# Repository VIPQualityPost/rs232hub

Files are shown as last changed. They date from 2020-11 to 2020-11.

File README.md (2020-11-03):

# rs232hub
This is a small project to make a USB-RS232 four port hub for use with SCPI commands for making an easy, automated testing controller. 
I successfully made the prototype with just one channel, but for the final design I want to incorporate a 4 port USB hub controller so I can have several devices connected at once.
I don't need USB3.0 speed so this will not include that, but it will feature a USB-C port to be consistent with other designs I have made (and I still have several connectors left over from previous projects)

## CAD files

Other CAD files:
Sketch.step
usbfootprint.FCStd

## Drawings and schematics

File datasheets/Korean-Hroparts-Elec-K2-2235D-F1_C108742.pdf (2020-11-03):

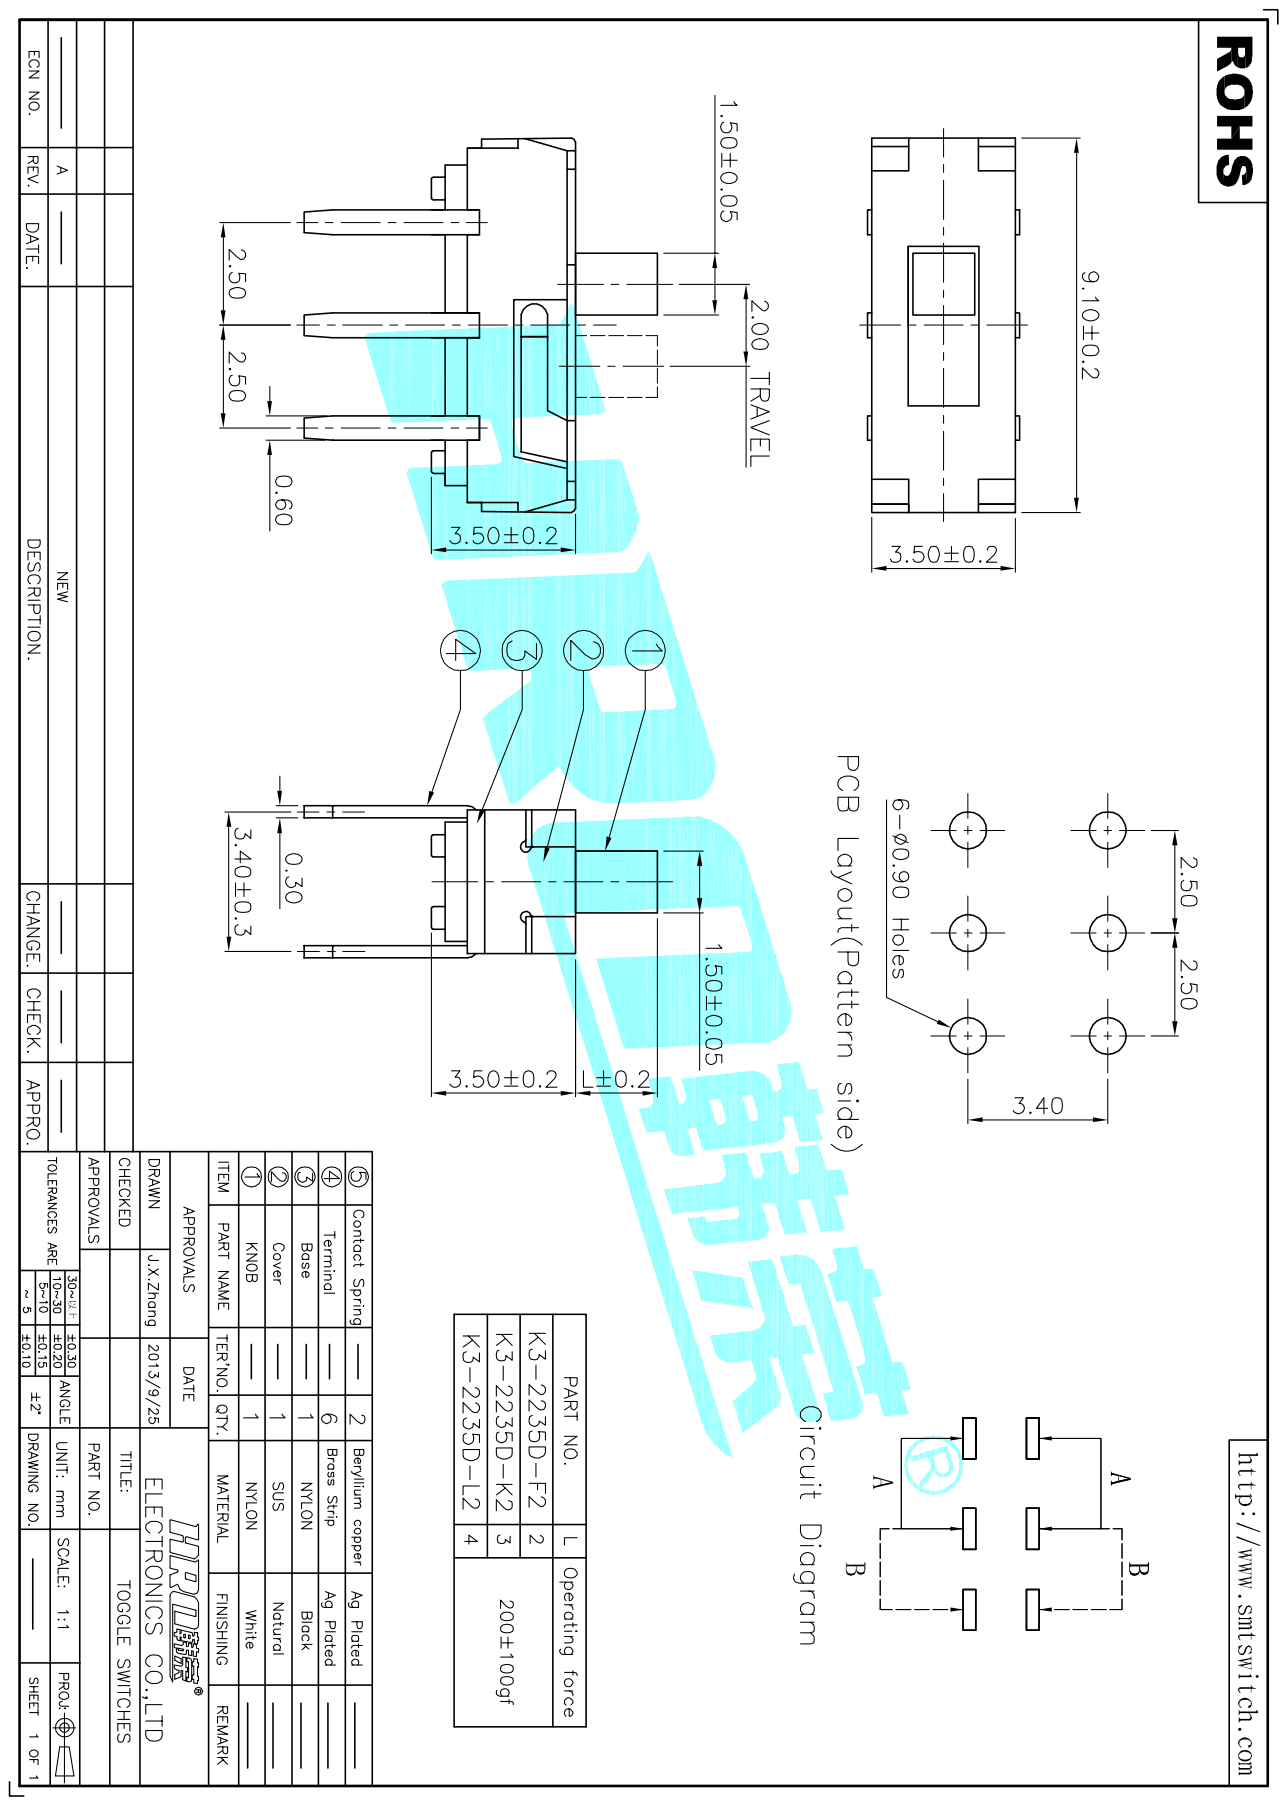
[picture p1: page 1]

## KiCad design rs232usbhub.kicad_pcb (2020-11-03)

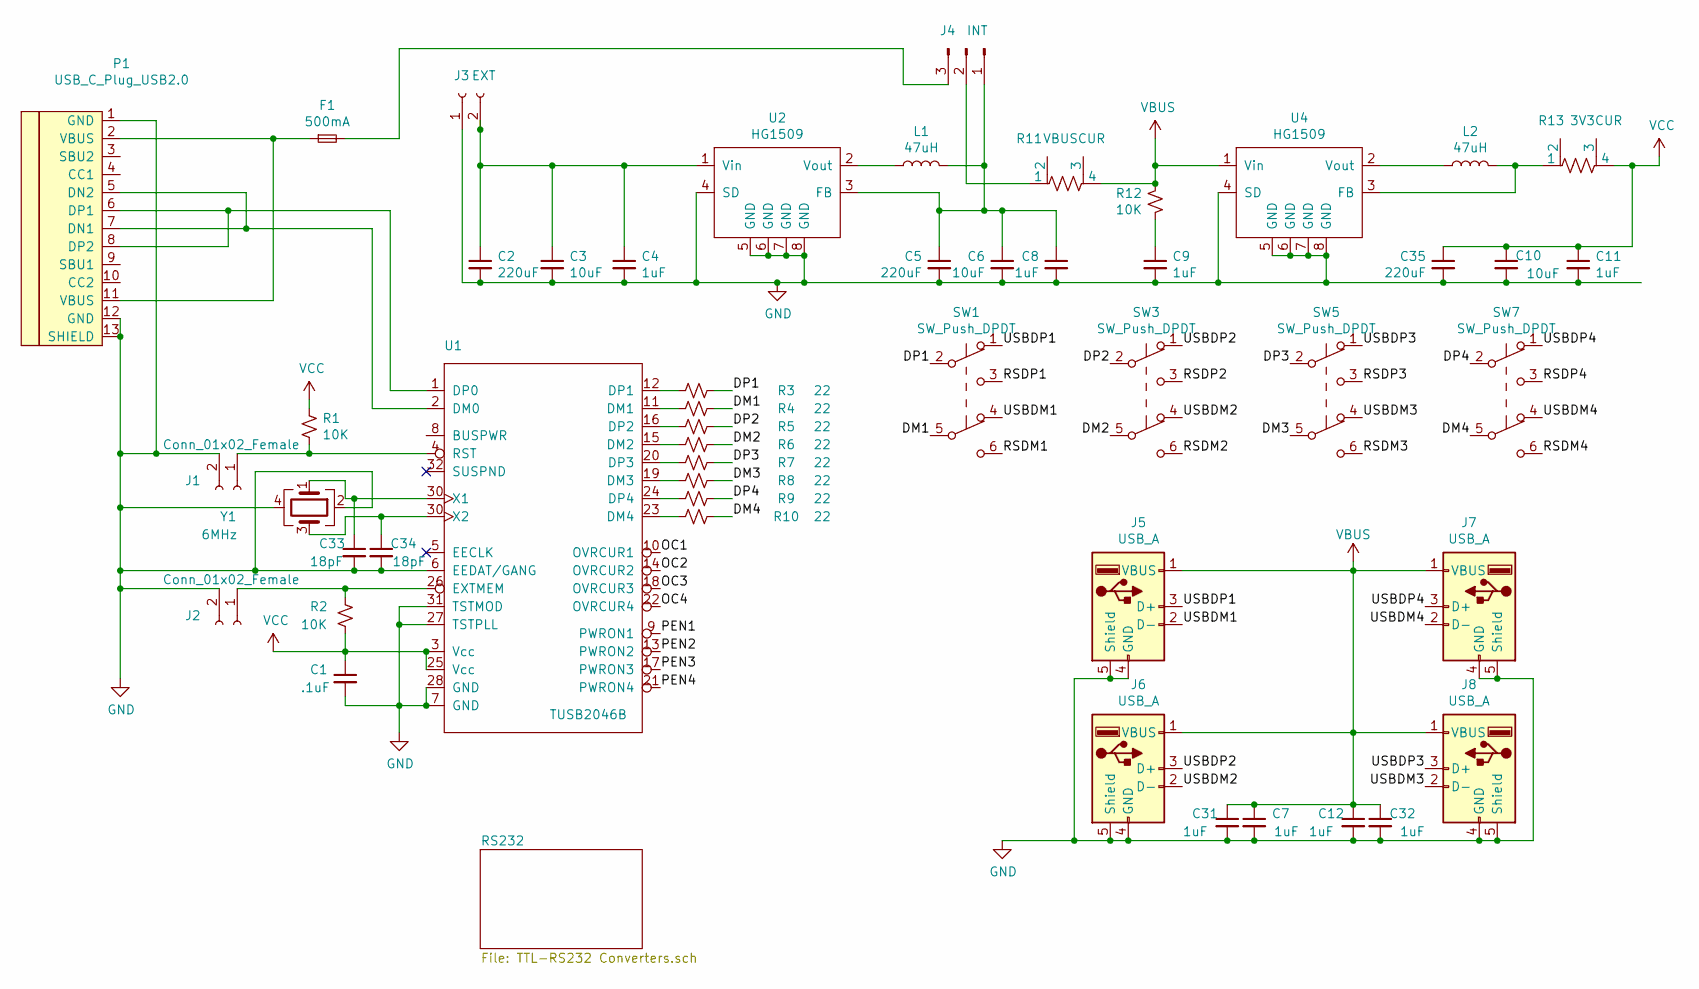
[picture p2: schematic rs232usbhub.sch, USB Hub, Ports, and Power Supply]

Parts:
C1: .1uF; C_0402_1005Metric_Pad0.74x0.62mm_HandSolder
C2, C5, C35: 220uF; CP_Elec_8x10.5
C3, C6, C10: 10uF; CP_Elec_4x5.4
C4, C7, C8, C9, C11, C12, C31, C32: 1uF; C_0402_1005Metric_Pad0.74x0.62mm_HandSolder
C33, C34: 18pF; C_0402_1005Metric_Pad0.74x0.62mm_HandSolder
F1: 500mA; C_0402_1005Metric_Pad0.74x0.62mm_HandSolder
J1, J2: Conn_01x02_Female; PinHeader_1x02_P1.00mm_Vertical
J3: EXT; BarrelJack_CLIFF_FC681465S_SMT_Horizontal
J4: INT; PinHeader_1x03_P2.54mm_Vertical
J5, J6, J7, J8: USB_A; USBA2LCSC109355
L1, L2: 47uH; L_12x12mm_H4.5mm
P1: USB_C_Plug_USB2.0; HRO-TYPE-C-31-M-12-HandSoldering
R1, R2, R12: 10K; R_0402_1005Metric_Pad0.72x0.64mm_HandSolder
R3, R4, R5, R6, R7, R8, R9, R10: 22; R_0402_1005Metric_Pad0.72x0.64mm_HandSolder
R11: VBUSCUR; R_0402_1005Metric_Pad0.72x0.64mm_HandSolder
R13: 3V3CUR; R_0402_1005Metric_Pad0.72x0.64mm_HandSolder
SW1, SW3, SW5, SW7: SW_Push_DPDT; SW_CuK_JS202011CQN_DPDT_Straight
U1: TUSB2046B; LQFP-32_7x7mm_P0.8mm
U2, U4: HG1509; SOP-8_3.9x4.9mm_P1.27mm
Y1: 6MHz; Crystal_SMD_EuroQuartz_MQ-4Pin_7.0x5.0mm_HandSoldering

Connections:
/DM1: R4.1, SW1.5 (B)
/DM2: R6.1, SW3.5 (B)
/DM3: R8.1, SW5.5 (B)
/DM4: R10.1, SW7.5 (B)
/DP1: R3.1, SW1.2 (B)
/DP2: R5.1, SW3.2 (B)
/DP3: R7.1, SW5.2 (B)
/DP4: R9.1, SW7.2 (B)
/OC1: U1.10 (OVRCUR1)
/OC2: U1.14 (OVRCUR2)
/OC3: U1.18 (OVRCUR3)
/OC4: U1.22 (OVRCUR4)
/PEN1: U1.9 (PWRON1)
/PEN2: U1.13 (PWRON2)
/PEN3: U1.17 (PWRON3)
/PEN4: U1.21 (PWRON4)
/RSDM1: SW1.6 (C)
/RSDM2: SW3.6 (C)
/RSDM3: SW5.6 (C)
/RSDM4: SW7.6 (C)
/RSDP1: SW1.3 (C)
/RSDP2: SW3.3 (C)
/RSDP3: SW5.3 (C)
/RSDP4: SW7.3 (C)
/USBDM1: J5.2 (D-), SW1.4 (A)
/USBDM2: J6.2 (D-), SW3.4 (A)
/USBDM3: J8.2 (D-), SW5.4 (A)
/USBDM4: J7.2 (D-), SW7.4 (A)
/USBDP1: J5.3 (D+), SW1.1 (A)
/USBDP2: J6.3 (D+), SW3.1 (A)
/USBDP3: J8.3 (D+), SW5.1 (A)
/USBDP4: J7.3 (D+), SW7.1 (A)
GND: C1.2, C2.2, C3.2, C4.2, C5.2, C6.2, C7.2, C8.2, C9.2, C10.2, C11.2, C12.2, C31.2, C32.2, C33.2, C34.2, C35.2, J1.2, J2.2, J3.1, J5.4 (GND), J5.5 (Shield), J6.4 (GND), J6.5 (Shield), J7.4 (GND), J7.5 (Shield), J8.4 (GND), J8.5 (Shield), P1.1 (GND), P1.12 (GND), P1.13 (SHIELD), U1.6 (EEDAT/GANG), U1.7 (GND), U1.27 (TSTPLL), U1.28 (GND), U1.31 (TSTMOD), U2.4 (SD), U2.5 (GND), U2.6 (GND), U2.7 (GND), U2.8 (GND), U4.4 (SD), U4.5 (GND), U4.6 (GND), U4.7 (GND), U4.8 (GND), Y1.2, Y1.4; also elsewhere on the board
unnamed: C2.1, C3.1, C4.1, J3.2, U2.1 (Vin)
unnamed: C5.1, C6.1, C8.1, J4.1, L1.2, U2.3 (FB)
unnamed: C9.1, R12.2
unnamed: F1.1, P1.2 (VBUS), P1.11 (VBUS)
unnamed: F1.2, J4.3
unnamed: J1.1, R1.2, U1.4 (RST)
unnamed: J2.1, R2.1, U1.26 (EXTMEM)
unnamed: J4.2, R11.1
unnamed: L1.1, U2.2 (Vout)
unnamed: L2.1, U4.2 (Vout)
unnamed: L2.2, R13.1, U4.3 (FB)
unnamed: P1.5 (DN2), P1.7 (DN1), U1.2 (DM0)
unnamed: P1.6 (DP1), P1.8 (DP2), U1.1 (DP0)
unnamed: R3.2, U1.12 (DP1)
unnamed: R4.2, U1.11 (DM1)
unnamed: R5.2, U1.16 (DP2)
unnamed: R6.2, U1.15 (DM2)
unnamed: R7.2, U1.20 (DP3)
unnamed: R8.2, U1.19 (DM3)
unnamed: R9.2, U1.24 (DP4)
unnamed: R10.2, U1.23 (DM4)
VBUS: C7.1, C12.1, C31.1, C32.1, J5.1 (VBUS), J6.1 (VBUS), J7.1 (VBUS), J8.1 (VBUS), R11.4, R12.1, U4.1 (Vin); also elsewhere on the board
VCC: C1.1, C10.1, C11.1, C35.1, R1.1, R2.2, R13.4, U1.3 (Vcc), U1.25 (Vcc)

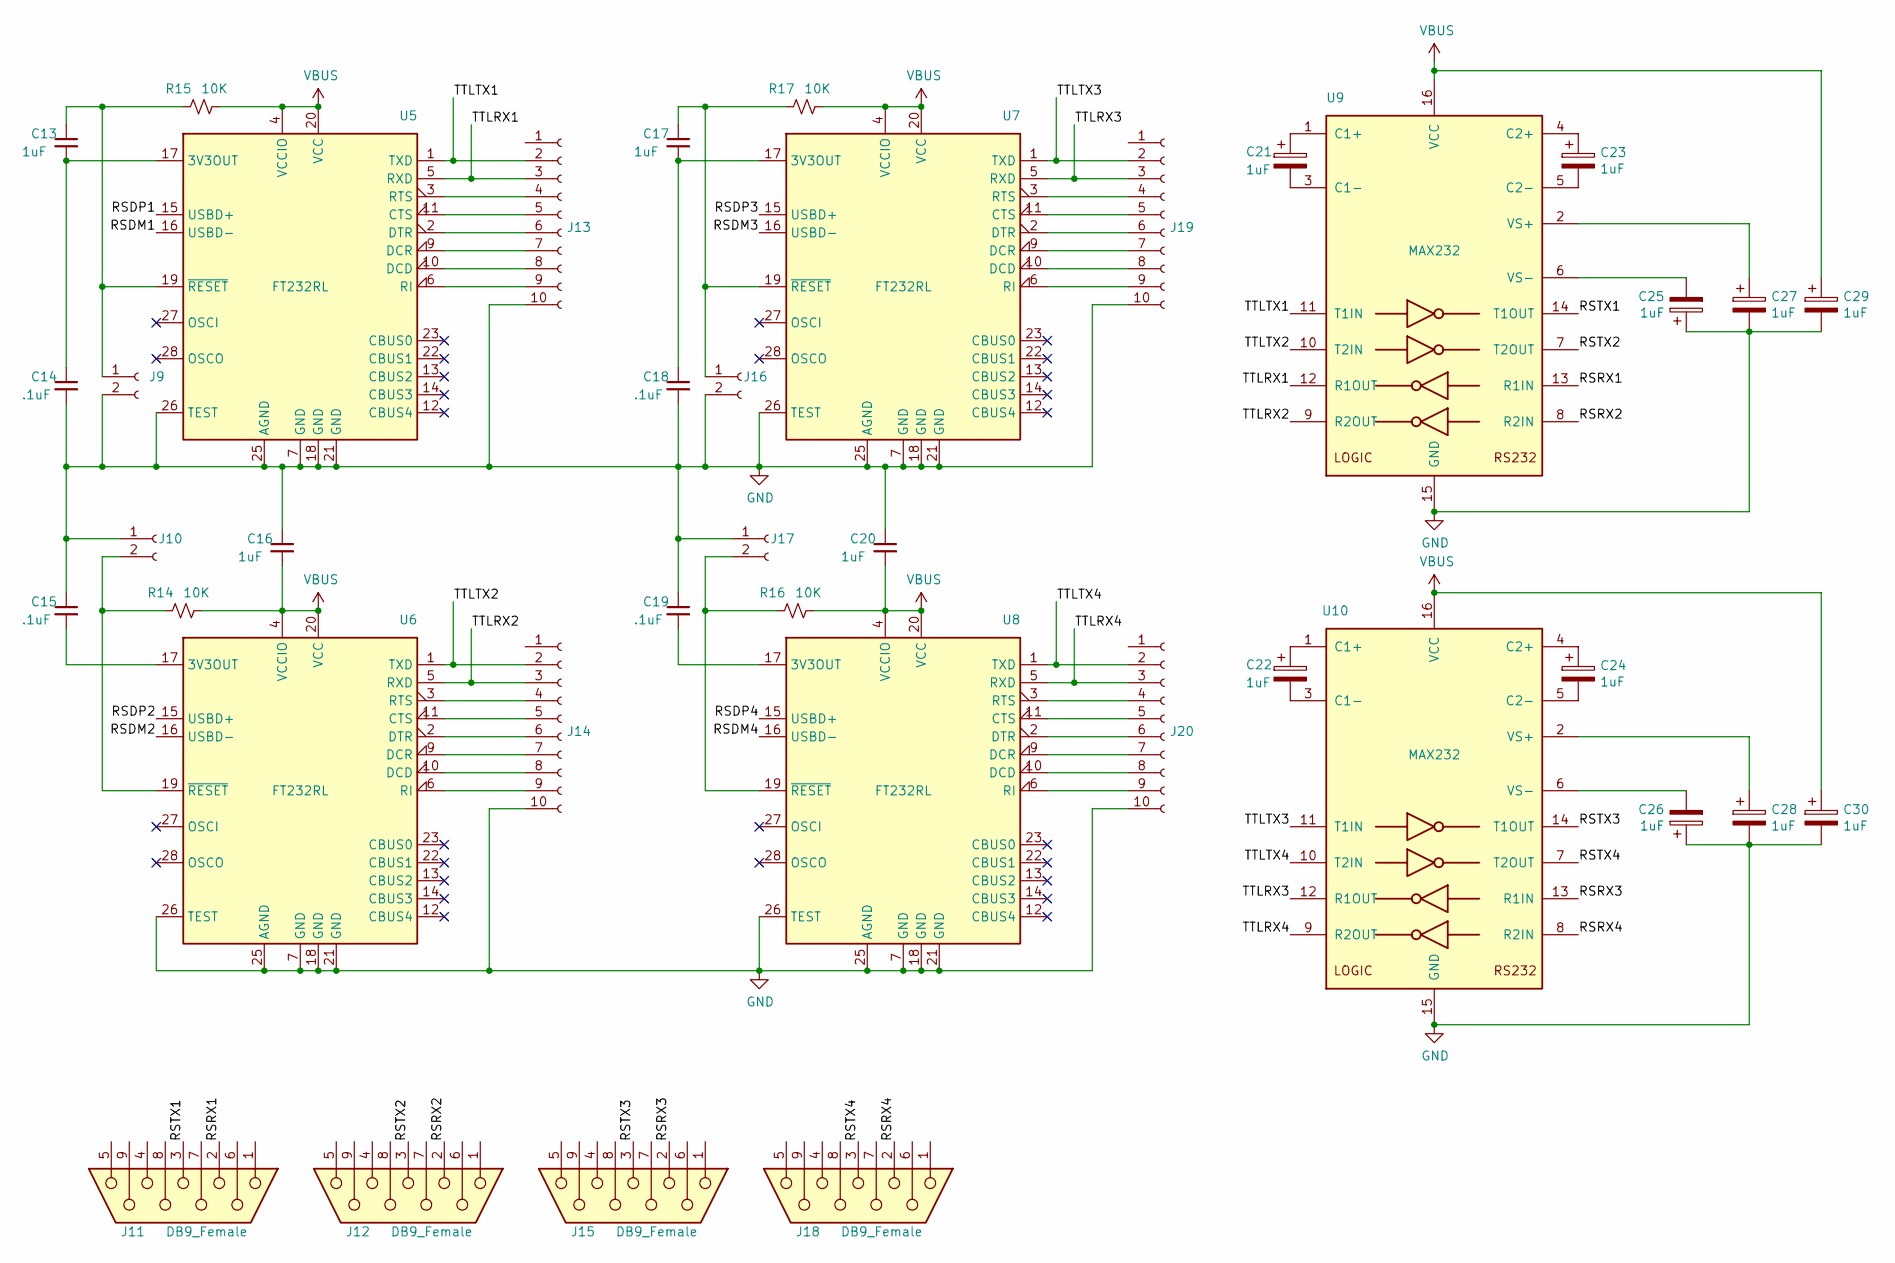
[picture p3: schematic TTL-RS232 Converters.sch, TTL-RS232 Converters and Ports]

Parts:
C13, C16, C17, C20: 1uF; C_0402_1005Metric_Pad0.74x0.62mm_HandSolder
C14, C15, C18, C19: .1uF; C_0402_1005Metric_Pad0.74x0.62mm_HandSolder
C21, C22, C23, C24, C25, C26, C27, C28, C29, C30: 1uF; CP_Elec_4x5.4
J9, J10, J16, J17: Conn_01x02_Female; PinHeader_1x02_P1.00mm_Vertical
J11, J12, J15, J18: DB9_Female; dsub9
J13, J14, J19, J20: Conn_01x10_Female; PinSocket_1x10_P2.54mm_Vertical
R14, R15, R16, R17: 10K; R_0402_1005Metric_Pad0.72x0.64mm_HandSolder
U5, U6, U7, U8: FT232RL; SSOP-28_5.3x10.2mm_P0.65mm
U9, U10: MAX232; SOIC-16_3.9x9.9mm_P1.27mm

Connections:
/RS232/RSDM1: U5.16 (USBD-)
/RS232/RSDM2: U6.16 (USBD-)
/RS232/RSDM3: U7.16 (USBD-)
/RS232/RSDM4: U8.16 (USBD-)
/RS232/RSDP1: U5.15 (USBD+)
/RS232/RSDP2: U6.15 (USBD+)
/RS232/RSDP3: U7.15 (USBD+)
/RS232/RSDP4: U8.15 (USBD+)
/RS232/RSRX1: J11.2, U9.13 (R1IN)
/RS232/RSRX2: J12.2, U9.8 (R2IN)
/RS232/RSRX3: J15.2, U10.13 (R1IN)
/RS232/RSRX4: J18.2, U10.8 (R2IN)
/RS232/RSTX1: J11.3, U9.14 (T1OUT)
/RS232/RSTX2: J12.3, U9.7 (T2OUT)
/RS232/RSTX3: J15.3, U10.14 (T1OUT)
/RS232/RSTX4: J18.3, U10.7 (T2OUT)
/RS232/TTLRX1: J13.3, U5.5 (RXD), U9.12 (R1OUT)
/RS232/TTLRX2: J14.3, U6.5 (RXD), U9.9 (R2OUT)
/RS232/TTLRX3: J19.3, U7.5 (RXD), U10.12 (R1OUT)
/RS232/TTLRX4: J20.3, U8.5 (RXD), U10.9 (R2OUT)
/RS232/TTLTX1: J13.2, U5.1 (TXD), U9.11 (T1IN)
/RS232/TTLTX2: J14.2, U6.1 (TXD), U9.10 (T2IN)
/RS232/TTLTX3: J19.2, U7.1 (TXD), U10.11 (T1IN)
/RS232/TTLTX4: J20.2, U8.1 (TXD), U10.10 (T2IN)
GND: C14.2, C15.1, C16.1, C18.2, C19.1, C20.1, C25.1, C26.1, C27.2, C28.2, C29.2, C30.2, J9.2, J10.1, J13.10, J14.10, J16.2, J17.1, J19.10, J20.10, U5.7 (GND), U5.18 (GND), U5.21 (GND), U5.25 (AGND), U5.26 (TEST), U6.7 (GND), U6.18 (GND), U6.21 (GND), U6.25 (AGND), U6.26 (TEST), U7.7 (GND), U7.18 (GND), U7.21 (GND), U7.25 (AGND), U7.26 (TEST), U8.7 (GND), U8.18 (GND), U8.21 (GND), U8.25 (AGND), U8.26 (TEST), U9.15 (GND), U10.15 (GND); also elsewhere on the board
unnamed: C13.1, J9.1, R15.1, U5.19 (~RESET~)
unnamed: C13.2, C14.1, U5.17 (3V3OUT)
unnamed: C15.2, U6.17 (3V3OUT)
unnamed: C17.1, J16.1, R17.1, U7.19 (~RESET~)
unnamed: C17.2, C18.1, U7.17 (3V3OUT)
unnamed: C19.2, U8.17 (3V3OUT)
unnamed: C21.1, U9.1 (C1+)
unnamed: C21.2, U9.3 (C1-)
unnamed: C22.1, U10.1 (C1+)
unnamed: C22.2, U10.3 (C1-)
unnamed: C23.1, U9.4 (C2+)
unnamed: C23.2, U9.5 (C2-)
unnamed: C24.1, U10.4 (C2+)
unnamed: C24.2, U10.5 (C2-)
unnamed: C25.2, U9.6 (VS-)
unnamed: C26.2, U10.6 (VS-)
unnamed: C27.1, U9.2 (VS+)
unnamed: C28.1, U10.2 (VS+)
unnamed: J10.2, R14.1, U6.19 (~RESET~)
unnamed: J13.4, U5.3 (RTS)
unnamed: J13.5, U5.11 (CTS)
unnamed: J13.6, U5.2 (DTR)
unnamed: J13.7, U5.9 (DCR)
unnamed: J13.8, U5.10 (DCD)
unnamed: J13.9, U5.6 (RI)
unnamed: J14.4, U6.3 (RTS)
unnamed: J14.5, U6.11 (CTS)
unnamed: J14.6, U6.2 (DTR)
unnamed: J14.7, U6.9 (DCR)
unnamed: J14.8, U6.10 (DCD)
unnamed: J14.9, U6.6 (RI)
unnamed: J17.2, R16.1, U8.19 (~RESET~)
unnamed: J19.4, U7.3 (RTS)
unnamed: J19.5, U7.11 (CTS)
unnamed: J19.6, U7.2 (DTR)
unnamed: J19.7, U7.9 (DCR)
unnamed: J19.8, U7.10 (DCD)
unnamed: J19.9, U7.6 (RI)
unnamed: J20.4, U8.3 (RTS)
unnamed: J20.5, U8.11 (CTS)
unnamed: J20.6, U8.2 (DTR)
unnamed: J20.7, U8.9 (DCR)
unnamed: J20.8, U8.10 (DCD)
unnamed: J20.9, U8.6 (RI)
VBUS: C16.2, C20.2, C29.1, C30.1, R14.2, R15.2, R16.2, R17.2, U5.4 (VCCIO), U5.20 (VCC), U6.4 (VCCIO), U6.20 (VCC), U7.4 (VCCIO), U7.20 (VCC), U8.4 (VCCIO), U8.20 (VCC), U9.16 (VCC), U10.16 (VCC); also elsewhere on the board

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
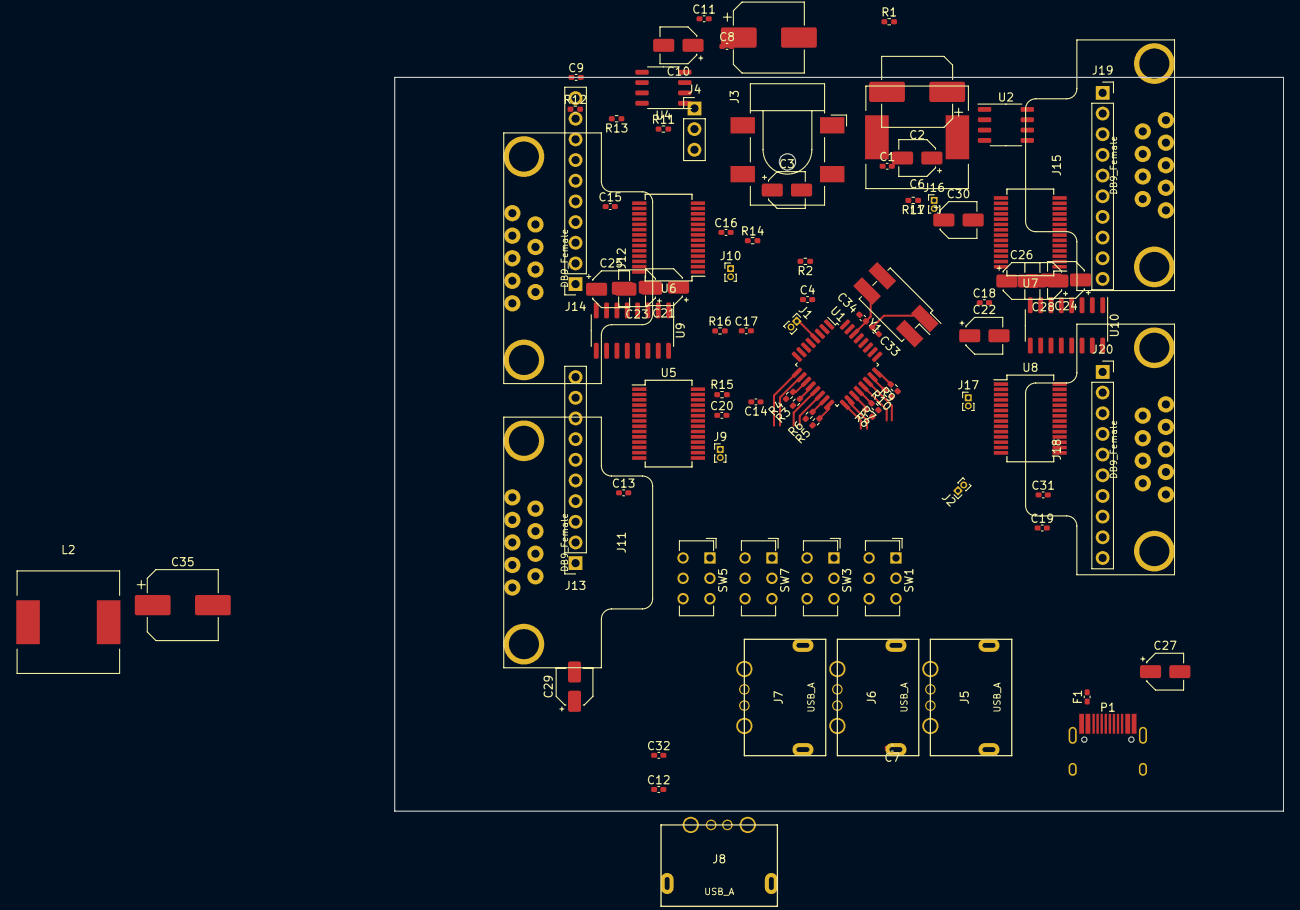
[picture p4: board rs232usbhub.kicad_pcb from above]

Board: 2 copper layers, 109.2 x 90.2 mm, 90 parts (0 on the bottom side), 102 nets.
